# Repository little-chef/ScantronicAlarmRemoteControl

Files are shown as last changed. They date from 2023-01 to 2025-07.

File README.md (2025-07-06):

# Scantronic 9751/9752 Alarm Remote Control 

:warning: *This project is read-only. There will be no follow up anymore.*:warning:

It is so much easier to reimplement this old Alarm system with:
* A [4-relay board based on an ESP32](https://lilygo.cc/products/t-relay). The relays are used for switching the siren, strobe light etc.
* Have 16 ADC inputs where the PIRs are connected to with existing resistors, for example [2 x MCP3008](https://www.microchip.com/en-us/product/MCP3008)
* Use the [ESPHome Alarm control panel component](https://esphome.io/components/alarm_control_panel/index.html) for implementing the state machine
* Control panel like this [Shelly Wall Display X2](https://kb.shelly.cloud/knowledge-base/shelly-wall-display-x2), to control Home Assistant and the Alarm System.
* Use a [nice metal box with power supply](https://www.elmdene.co.uk/12v-power-supplies/standby-power-security) and battery back up for housing the whole thing.
Wire it all up, create some firmware for the ESP32, and let it run.
Other advantages are that it enables remote access and PIRs can be used when the alarm is unarmed for detecting room occupance.

## Introduction

The Scantronic 9751/9752 alarm system is a burglary alarm system. This alarm device allows you to integrate all wired detectors
and wireless components, turning it into a hybrid system. It can be extended up to 32 alarm zones.
The motherboard offers 8 freely programmable zones for 8 wired detector, the remaining zones can be extended via 9954
extension modules and 9960 wireless extension modules. Control panels are typically the 9930 panels.

The Scantronic 9752 alarm system does not offer an interface to connect the system to a home-automation system,
neither is there an option to remote control the alarm system via the internet.
Reporting alarms is done via a legacy PSTN land line by dialing some phone number, and there is no mechanism to reset the alarm
remotely.
For home-automation systems it is useful to detect people presence in various rooms, the alarm system already has a number of
PIRs connected to it, these are working 24/7, so the information these PIRs gather can ideally be reused for home automation purposes.
Also the system supports fire-alarms detectors that can be reused to remote monitor these statuses.

This project is created to provide remote control support and export information to a home automation project like Home-Assistant
via the ESPHome Addon.

This first revision of the project contains the documentation of the external peripheral interface where this project will hook in
to remotely control the alarm system.

## Alarm Systems supported
The Scantronic 9752 wired alarm system is no longer new available but has been rebranded over time to 'Abus Terxon MX'.
The rebranded devices still have the same mainboard and peripherals and still the same limitations apply, like reporting alarms
via PSTN lines only and still no remote control support.
The expectation is that this project also works unmodified on these Abus Terxon MX systems.
The Terxon MX unit AZ4100/AZ4150 are equivalent to Scantronic 9751/9752, and the AZ4110 is equivalent to Scantronic 9930.
The AZ4130 is equivalent to the Scantronic 9954 extension unit.

## The Peripheral Interface

The Peripheral interface of the control panels to the main controller is described [here](docs/Protocol.md)

## Schematics for connecting an ESP32 as alarm system controller

The Schematics of the ESP32 based control board can be found [here](docs/Schematics.md)

## ESPHome Software Installation in Home Assistant

Here are the installation steps for the software in ESPHome:
* First install the ESPHome toolset on Home Assistant via the Addon Store.
* Open an SSH session to your Home-Assistant instance, then
  ```
  $ cd config
  $ git clone https://github.com/little-chef/ScantronicAlarmRemoteControl.git esphome/scantronic-alarm-control
  $ echo '<<: !include scantronic-alarm-control/alarm-control.yaml' > esphome/scantronic-alarm-control.yaml
  ```
  Next create the secrets.yaml file in the /config directory and add the following lines:
  ```
  esphome_hassio_api_encryption_key: my-32-byte-base64-encryption-key
  esphome_hassio_ota_pw: my-very-secure-ota-pw
  esphome_wifi_network_ssid: my-wifi-access-point
  esphome_wifi_network_password: my-wifi-password
  esphome_wifi_ap_fallback_password: my-fallback-password
  ```
  The api_encryption key is explained here: https://esphome.io/components/api.html?highlight=randomly%20generated

* Go to the ESPHome dashboard on Home Assistant, the new device should be visible. From
  here you can compile the firmware for the ESP32 device, and install it to ESP32 device.
* Once the device is running, a new notification will pop up to register the device to your
  Home Assistant instance. Complete that procedure.
* After everything is successful, the controller will become visible on the Home Assistant Dashboard.

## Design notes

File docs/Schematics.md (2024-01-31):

# Scantronic 9751/9752 Alarm Remote Control Peripheral interface Schematics

This is an initial schematics version for adding an ESP32 to emulate the control panel. (NOT TESTED YET!)

We use a LIN-bus transceiver as level shifter from 12v line level to 3v3 for the ESP32, and a simple transistor for converting the
clock signal to a proper 3v3 level, this inverts the clock signal, but that can be solved by selecting the proper SPI mode.
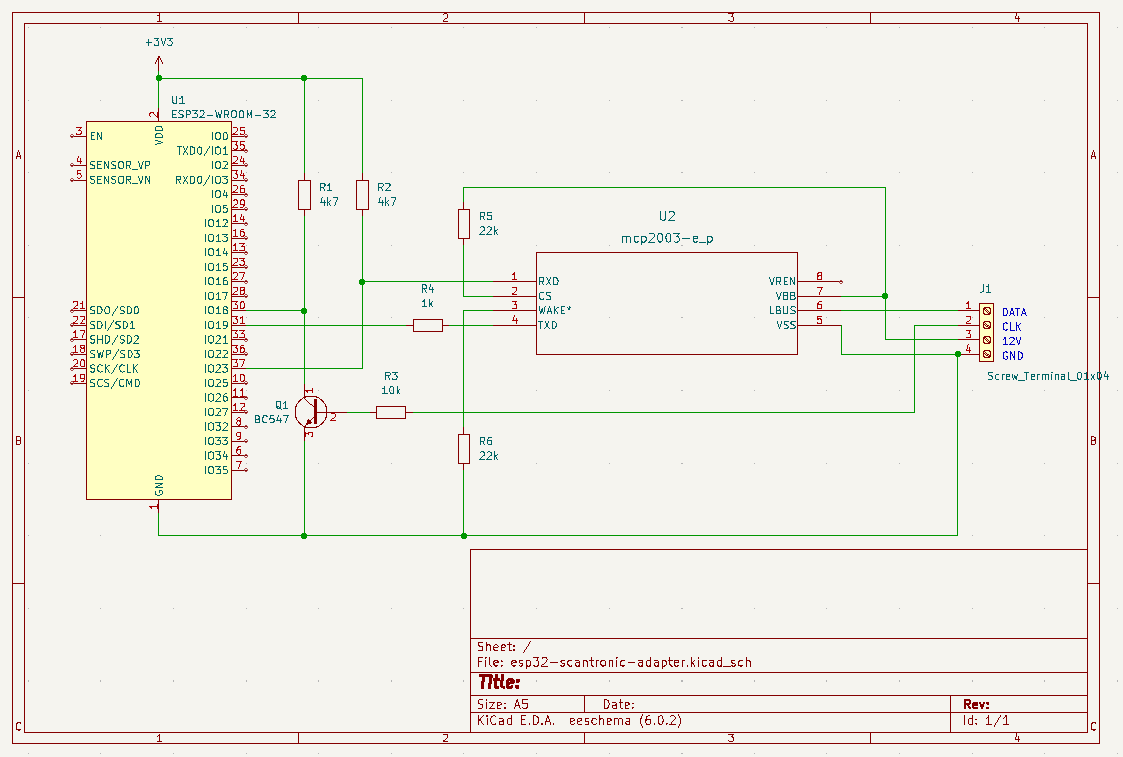
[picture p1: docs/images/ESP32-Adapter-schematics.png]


The schematics are designed with KiCAD, and can be found in the schematics folder

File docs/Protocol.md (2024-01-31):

# Scantronic 9751/9752 Alarm Remote Control Peripheral interface and communication protocol

This page describes the Peripheral interface and communication protocol in detail.

## The Peripheral Interface

The Alarm System contains an interface to which the extension unit and the Control
Panels are connected. This is a 4-pin connector with these connections:
* 0V
* 12V
* CLK
* DATA

Only the data from the control panel and from the extension board is available on this connector. All PIRs connected to the main board are not visible on this interface. Neither is the status of the Alarm System directly visible on this port since the communication is stateless.

The DATA and CLK lines are based on a [Synchronous Serial Interface](https://en.wikipedia.org/wiki/Synchronous_Serial_Interface).
This is the typical structure of a data frame:
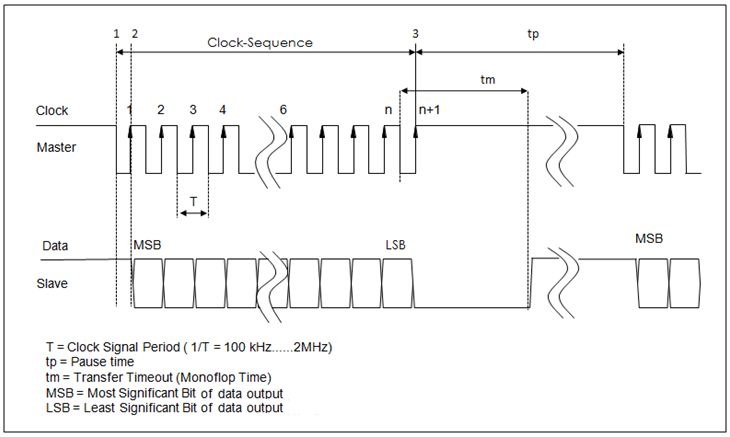
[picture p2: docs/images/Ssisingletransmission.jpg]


Some details:
* The communication is half-duplex. There is only 12V/GND, the signal is not differential.

  Note that there is no difference between Tx/Rx: All incoming and outgoing data is mapped to the same DATA line. The device that pulls down the
  DATA line first has the control of the bus.
* When idle, the CLK and DATA lines are on a +12 Volt level, and in tri-state mode.
* Data starts when the CLK line goes from High to low (1). All bits are read on each rising edge (2-3).
* T is nominal about 500uS, leading to max. 2kHz clock frequency, but there is some variation on the stability of the clock (T=500uS - 540uS).
* Each byte is seperated by about 1 millisecond pause, the distance between 2 messages (tp) is minimal 5ms.
* Max length of a single message is 21 bytes.

Example messages:
|1 long message|2 messages in a sequence|1 short message|
|---|---|---|
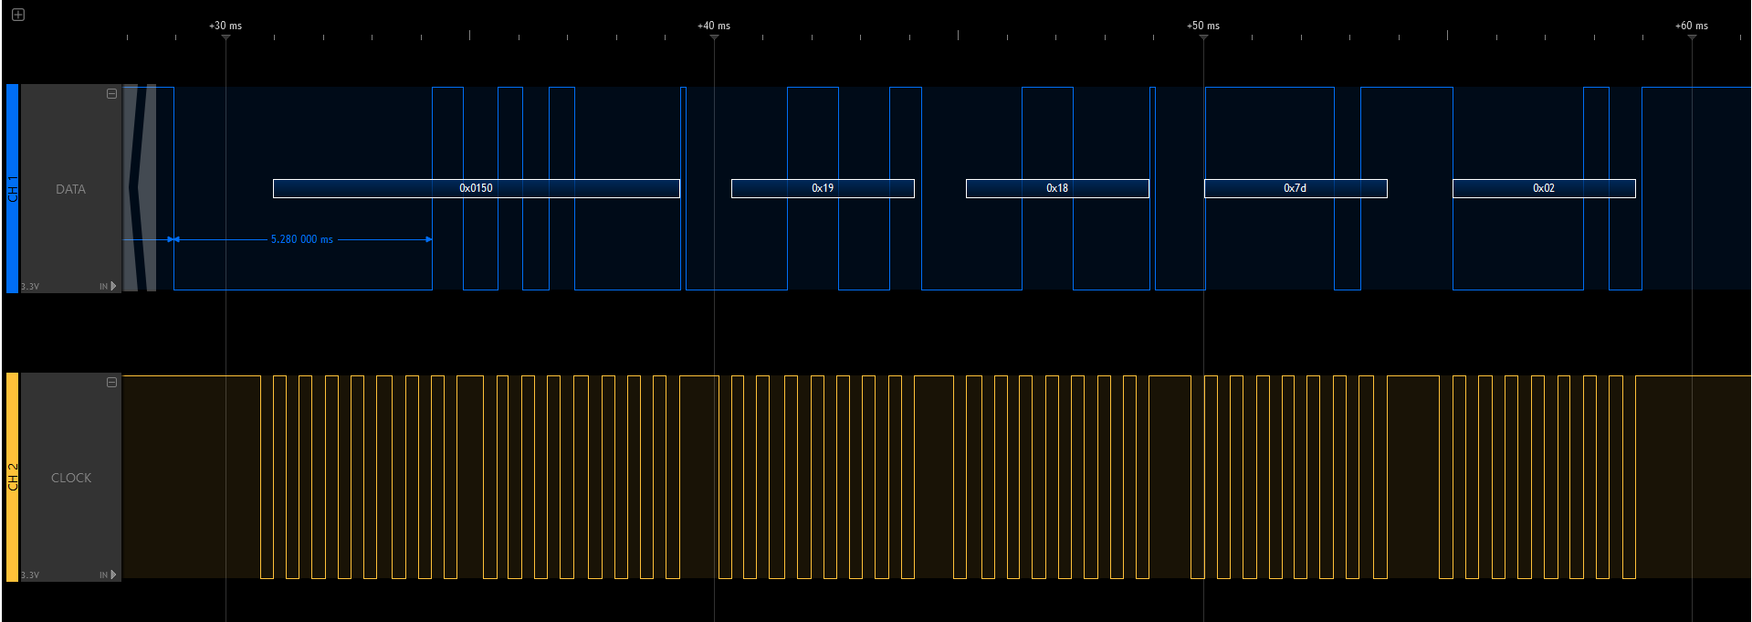
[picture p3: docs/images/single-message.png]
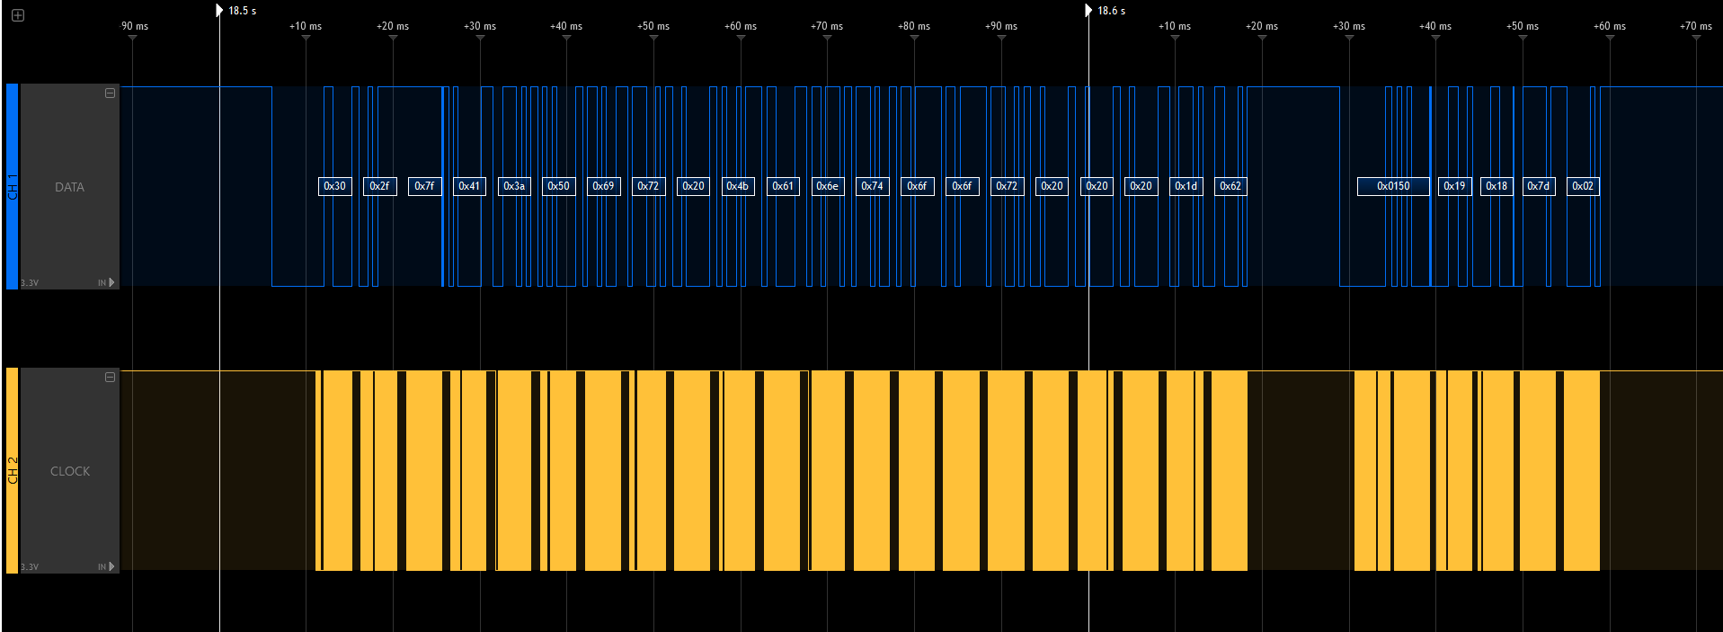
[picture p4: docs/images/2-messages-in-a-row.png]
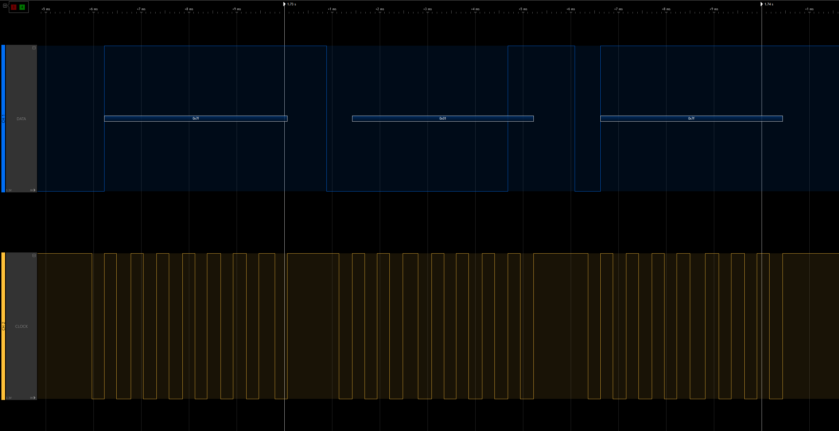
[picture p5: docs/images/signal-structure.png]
||||

All messages contain a checksum mechanism:
* All messages are a sequence of 8-bit bytes.
* A checksum is calculated and appended to each stream of bytes as 2 independent bytes, although some messages only use 1 checksum value.
* The formula to calculate a checksum is like this:
  * CHKSUM1 = Calculated as "0x7f - CHKSUM2"
  * CHKSUM2 = (BYTE0 + BYTE1 + BYTE2 + ... + BYTE_N) & 0x7f
    (= add up all the bytes in the message, except the checksum bytes en bitwise OR it with 0x7f)

## Interface to the control panels

The Control Panels are 'dumb' devices, which means they do not maintain state of the alarm system:
* All key presses are sent to the main board immediately after pressing any key. The main board responds with what the control panel needs to display.
* All messages on the screen are only sent to the control panel that initiated the activity. All data traffic is unencrypted.
* Some information, like date and time, is broadcasted to all panels.

### Key press data format

All key presses follow this data structure.

|BYTE0|BYTE1|BYTE2|BYTE3|BYTE4|BYTE5|
|---|---|---|---|---|---|
|DEST|SRC|DATA0|DATA1|CHKSUM1|CHKSUM2|

* DEST: The ID of the Main Control Board, always: 0x00
* SRC:  The ID of the Control Panel that sents the message: 0x30 for the 1st control panel, 0x31 for the 2nd.
* DATA0: 0x00
* DATA1: The ASCII code for the button pressed:
    |Key|Value|\||Key|Value|
    |---|---|---|---|---|
    |0|0x30|\||A|0x41|
    |1|0x31|\||B|0x42|
    |2|0x32|\||C|0x43|
    |3|0x33|\||D|0x44|
    |4|0x34|\||V|0x0d (=Enter)|
    |5|0x35|\||X|0x1b (=ESC)|
    |6|0x36|\||||
    |7|0x37|\||||
    |8|0x38|\||||
    |9|0x39|\||||
* CHKSUM1 = see above
* CHKSUM2 = see above

### Control Panel display update

All lines to be displayed on the screen are sent in plain text from the mainboard to the control panel.
The control panel simply displays what it receives from the main control panel.

There are 2 options:
1) message specific for 1 control panel
2) Broadcast of a message to all panels.

#### Option 1: Message for a single panel
|BYTE0|BYTE1|BYTE2|BYTE3-BYTE18|BYTE19|BYTE20|
|---|---|---|---|---|---|
|DEST|LINE|0x7F|TEXT|CHKSUM1|CHKSUM2|

* DEST: The ID of the Control Panel: 0x30 for the 1st panel, 0x31 for the 2nd panel.
* LINE:
    * 0x2F = The 1st line on the screen
    * 0x4F = The 2nd line of the screen
* TEXT: Always 16 bytes of ASCII data to be displayed on the screen.
* CHKSUM1 = see above
* CHKSUM2 = see above

#### Option 2: Boardcast message to all panels
|BYTE0|BYTE1|BYTE2|BYTE3-BYTE18|BYTE19|
|---|---|---|---|---|
|DEST|LINE|0x7F|TEXT|CHKSUM1|

* DEST: 0x3f
* LINE:
    * 0x2F = The 1st line on the screen
    * 0x4F = The 2nd line of the screen
* TEXT: Always 16 bytes of ASCII data to be displayed on the screen.
* CHKSUM1 = see above (CHKSUM2 is NOT sent to the panel in case of broadcast).

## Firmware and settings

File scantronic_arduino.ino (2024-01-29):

#include <SPI.h>

/*
You will need to connect the 12V pin to the VIN of the Arduino board, 
the GND pin to the GND of the Arduino board, and the DATA pin 
to both the MOSI and MISO pins of the Arduino board.
You will also need a resistor (e.g. 10k ohm) 
between the DATA pin and the GND pin to create a pull-down effect. 
*/

// Define the pins used for SPI communication 
#define CS_PIN 10 // Chip select pin 
#define MOSI_PIN 11 // Master out slave in pin 
#define MISO_PIN 12 // Master in slave out pin 
#define SCK_PIN 13 // Serial clock pin

// Define the number of bytes to read from the alarm panel 
#define DATA_LENGTH 21

// Define the timing parameters of the alarm panel in microseconds 
#define T 500 

// Clock signal period 
#define TP 5000 

// Pause time between messages 
#define TRM 1000 // Transfer time between bytes

// Create a buffer to store the data 
byte data[DATA_LENGTH];

void setup() { // Initialize serial communication at 9600 baud rate 
  Serial.begin(9600);

  // Set the chip select pin as output and set it high 
  pinMode(CS_PIN, OUTPUT); 
  digitalWrite(CS_PIN, HIGH);

  // Set the SPI settings: mode 0, MSB first, external clock 
  SPISettings settings(0, MSBFIRST, EXTERNAL);

  // Initialize SPI communication with the settings 
  SPI.begin(); 
  SPI.beginTransaction(settings);
}

void loop() { 
  // Set the chip select pin low to start communication 
  digitalWrite(CS_PIN, LOW);

  // Wait for the clock line to go from high to low 
  while (digitalRead(SCK_PIN) == HIGH) {}

  // Read DATA_LENGTH bytes from the alarm panel and store them in the buffer 
  for (int i = 0; i < DATA_LENGTH; i++) {
    data[i] = SPI.transfer(0x00); // Send dummy byte to receive data

    // Wait for TRM microseconds before reading the next byte
    delayMicroseconds(TRM);
  }

  // Set the chip select pin high to end communication 
  digitalWrite(CS_PIN, HIGH);

   if (check_checksum(data, DATA_LENGTH)) { 
      // Check if byte 0 is between 0x30 and 0x39 (text panel display update message) 
      if (data[0] >= B00110000 && data[0] <= B00111001) { 
        // Parse and print the text panel display update messages to the serial monitor 
        parse_text_panel_display_update(data, DATA_LENGTH); 
      } // Check if byte 0 is 0x00 (key press data) 
      else if (data[0] == B00000000) {
        // Parse and print the key presses to the serial monitor 
        parse_key_presses(data, DATA_LENGTH); 
      } // Check if byte 0 is 0x3f (broadcast message to all panels) 
      else if (data[0] == B00111111) { 
        // Parse and print the broadcast message to all panels to the serial monitor 
        parse_broadcast_message(data, DATA_LENGTH); 
      } 
      else {
        // Print a message to the serial monitor that this is an unknown message type 
        Serial.println("Unknown message type."); 
      }

    } else { 
      // Print an error message to the serial monitor 
      Serial.println("Invalid checksum!"); 
    }

  // Wait for TP microseconds before reading again 
  delayMicroseconds(TP); 
}

// A function that calculates and verifies the checksum of a given array of bytes 
bool check_checksum(byte* array, int length) {

// Initialize variables to store the checksum values 
byte chksum1 = array[length - 2]; // The first checksum byte is at index length - 2 
byte chksum2 = array[length - 1]; // The second checksum byte is at index length - 1

// Calculate the expected checksum values based on the formula given by the user 
byte expected_chksum2 = 0; 
// Initialize expected_chksum2 as zero 
for (int i = 0; i < length - 2; i++) {
   // Loop through all bytes except the checksum bytes 
   expected_chksum2 += array[i]; 
   // Add each byte to expected_chksum2 
   expected_chksum2 &= B01111111; 
   // Bitwise AND with B01111111 (0x7f) to keep only the lower seven bits 
   //(this is equivalent to modulo by B10000000 (128)) 
   //(this is also equivalent to using a mask of B01111111) 

   } 
   byte expected_chksum1 = B01111111 - expected_chksum2; // Calculate expected_chksum1 as B01111111 (0x7f) minus expected_chksum2

  // Compare the actual checksum values with the expected checksum values 
  if (chksum1 == expected_chksum1 && chksum2 == expected_chksum2) {
   return true; // The checksum is valid 
  } 
  else 
  { 
     return false; // The checksum is invalid 
  } 
}

// A function that parses and prints the key presses from a given array of bytes 
void parse_key_presses(byte* array, int length) {

  // Initialize variables to store the key press information 
  byte key_code = array[1]; // The second byte is the key type 
  byte key_data = array[2]; // The third byte is the key data

  // Print the key press information to the serial monitor 
  Serial.print("Key press: ");


  // Check the key code and print the corresponding message 
switch (key_code) { 
  case 0x00: // Key code 0:  
  Serial.println("Key 0 pressed"); break; 
  case 0x01: // Key code 1: 
  Serial.println("Key 1 pressed"); break; 
  case 0x02: // Key code 2:
  Serial.println("Key 2 pressed"); break; 
  case 0x03: // Key code 3: 
  Serial.println("Key 3 pressed"); break; 
  case 0x04: // Key code 4: 
  Serial.println("Key 4 pressed"); break; 
  case 0x05: // Key code 5: 
  Serial.println("Key 5 pressed"); break; 
  case 0x06: // Key code 6: 
  Serial.println("Key 6 pressed"); break; 
  case 0x07: // Key code 7: 
  Serial.println("Key 7 pressed"); break; 
  case 0x08: // Key code 8: 
  Serial.println("Key 8 pressed"); break; 
  case 0x09: // Key code 9: 
  Serial.println("Key 9 pressed"); break; 
  case 0x0A: // Key code A: 
  Serial.println("Key A pressed"); break; 
  case 0x0B: // Key code B: 
  Serial.println("Key B pressed"); break; 
  case 0x0C: // Key code C: 
  Serial.println("Key C pressed"); break; 
  case 0x0D: // Key code D: 
  Serial.println("Key D pressed"); break; 
  case 0x0E: // Key code E:  
  Serial.println("Key E pressed"); break; 
  case 0x0F: // Key code F:
  Serial.println("Key F pressed"); break; 
  default: // Unknown key code 
  Serial.println("Unknown key code"); break; 
}

/*switch (key_code) { 
  case B00000000: // Key code 0:  
  Serial.println("Key 0 pressed"); break; 
  case B00000001: // Key code 1: 
  Serial.println("Key 1 pressed"); break; 
  case B00000010: // Key code 2:
  Serial.println("Key 2 pressed"); break; 
  case B00000011: // Key code 3: 
  Serial.println("Key 3 pressed"); break; 
  case B00000100: // Key code 4: 
  Serial.println("Key 4 pressed"); break; 
  case B00000101: // Key code 5: 
  Serial.println("Key 5 pressed"); break; 
  case B00000110: // Key code 6: 
  Serial.println("Key 6 pressed"); break; 
  case B00000111: // Key code 7: 
  Serial.println("Key 7 pressed"); break; 
  case B00001000: // Key code 8: 
  Serial.println("Key 8 pressed"); break; 
  case B00001001: // Key code 9: 
  Serial.println("Key 9 pressed"); break; 
  case B00001010: // Key code A: 
  Serial.println("Key A pressed"); break; 
  case B00001011: // Key code B: 
  Serial.println("Key B pressed"); break; 
  case B00001100: // Key code C: 
  Serial.println("Key C pressed"); break; 
  case B00001101: // Key code D: 
  Serial.println("Key D pressed"); break; 
  case B00001110: // Key code E:  
  Serial.println("Key E pressed"); break; 
  case B00001111: // Key code F:
  Serial.println("Key F pressed"); break; 
  default: // Unknown key code 
  Serial.println("Unknown key code"); break; 
  }
  */


  // Print the key data to the serial monitor in hexadecimal format 
  Serial.print("Key data: "); 
  if (key_data < 0x10) { 
    Serial.print("0"); // Add leading zero if necessary 
  }

  Serial.println(key_data, HEX);
}

void parse_broadcast_message(byte* array, int length) {

  // Initialize variables to store the broadcast message information 
  byte line = array[1]; 
  // The second byte is the line number on all panels 
  char text[17]; // A character array to store the text on all panels

  // Copy the text from the data buffer to the character array 
  for (int i = 0; i < 16; i++) { 
    // Loop through bytes 2 to 17 (16 bytes of ASCII data) 
    text[i] = char(array[i + 2]); // Convert each byte to a character and store it in the array
    }

  // Add a null terminator at the end of the character array 
  text[16] = '\0';

  // Print the broadcast message information to the serial monitor 
  Serial.print("Broadcast message to all panels: ");

  // Print the line number in decimal format 
  Serial.print("Line ");
  Serial.print(line, DEC);

  // Print the text in quotation marks 
  Serial.print(""""); 
  Serial.print(text); 
  Serial.println(""""); 
}


void parse_text_panel_display_update(byte* array, int length) {

  // Initialize variables to store the text panel display update information 
  byte dest = array[3]; // The fourth byte is the destination panel number 
  byte line = array[4]; // The fifth byte is the line number on the panel 
  char text[17]; // A character array to store the text on the panel

  // Copy the text from the data buffer to the character array 
  for (int i = 0; i < 16; i++) { // Loop through bytes 5 to 20 (16 bytes of ASCII data) 
  text[i] = char(array[i + 5]); // Convert each byte to a character and store it in the array 
  }

  // Add a null terminator at the end of the character array 
  text[16] = '\0';

  // Print the text panel display update information to the serial monitor 
  Serial.print("Text panel display update: ");

  // Print the destination panel number in decimal format 
  Serial.print("Panel "); 
  Serial.print(dest, DEC);

  // Print the line number in decimal format 
  Serial.print(" Line "); 
  Serial.print(line, DEC);

  // Print the text in quotation marks 
  Serial.print(""); 
  Serial.print(text); 
  Serial.println(""); 
}
